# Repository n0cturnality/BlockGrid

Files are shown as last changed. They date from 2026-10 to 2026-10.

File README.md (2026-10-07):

<p align="center">
  <picture>
    <source media="(prefers-color-scheme: dark)" srcset="docs/images/blockgrid-wordmark-dark.svg">
    BlockGrid
  </picture>
</p>

<h3 align="center">A desk-size Bitcoin dashboard built on a HUB75 LED matrix and an ESP32</h3>

<br>

<p align="center">
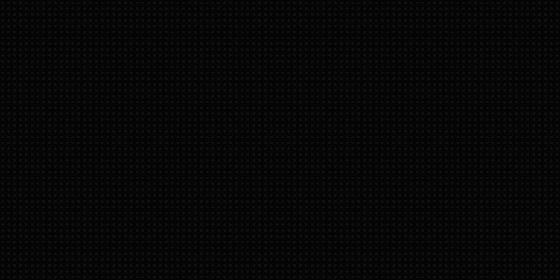
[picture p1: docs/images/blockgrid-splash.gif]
The boot splash: green digital rain of katakana and digits decodes into the word BLOCKGRID.
  
</p>

<p align="center">
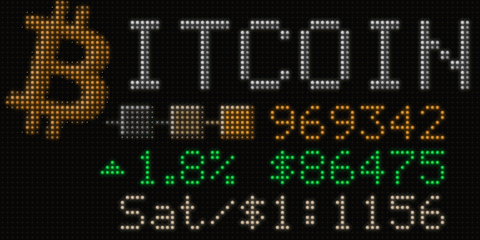
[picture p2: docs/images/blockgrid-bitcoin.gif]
The main screen with the Bitcoin logo: a new block slides onto the chain as the price in dollars changes, then it switches to euros and another block arrives with another price change.
  
  &nbsp;
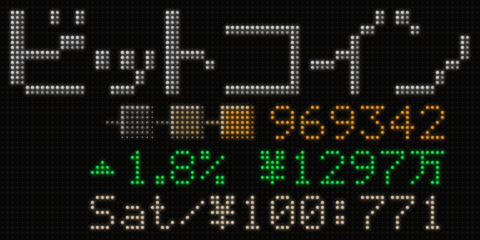
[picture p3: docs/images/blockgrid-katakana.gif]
The main screen with ビットコイン, Bitcoin in Japanese katakana, and the price in yen: two new blocks arrive, each with a price change.
  
</p>

BlockGrid shows the current block height, the price and its 24-hour change, and how many sats a dollar, euro or ¥100 buys. Two optional buttons on the back adjust the brightness and switch between the different looks and currency pairs. Everything else, from Wi-Fi to data sources, is set on a web page from your phone or computer.

<p align="center">
  <a href="https://n0cturnality.github.io/BlockGrid/">Live demo</a>
  &nbsp;
  <a href="#what-you-need">Build your own</a>
</p>

<br>

## Features

**Display**
- **Block height:** the chain tip, checked every 60 seconds.
- **Price:** in USD, EUR or JPY, with the 24-hour change and sats per $1, €1 or ¥100. Yen is shown in 万 (units of 10,000), the way large amounts are written in Japan.
- **Price effect:** roll, flash, sweep or none.
- **Two looks:** the Bitcoin logo, or ビットコイン in Japanese katakana.
- **Brightness:** 21 steps from 1 to 255, plus display off.
- **Flicker-free output:** double-buffered DMA drive of the HUB75 panel, at 6-bit colour per channel.

**Data sources**
- **Block height:** the mempool.space REST API, failing over to blockstream.info, or **your own node**: a mempool instance on a Start9, Umbrel or similar, over HTTP or HTTPS (self-signed certificates accepted), with the public APIs as fallback.
- **Price:** CoinGecko, failing over to mempool.space for the price and Coinbase for the 24-hour change. Polling interval adjustable from 30 seconds to 10 minutes (default 5).
- **Rate-limit handling:** after a 403 or 429 from CoinGecko it backs off for 10, then 30, then 60 minutes. When a source fails, the last good values stay on screen and are flagged as stale.

**Setup and control**
- **Captive-portal Wi-Fi setup:** BlockGrid starts its own password-protected access point. Joining it from a phone opens the setup page automatically, with a scan of nearby networks and their signal strength; hidden networks can be entered by name.
- **Web control page:** served at `http://blockgrid-xxxx.local` (mDNS) or the device's IP address. It covers brightness, display on/off, look, currency, price effect, data sources, polling interval, Wi-Fi and device status, and refreshes every 5 seconds from a JSON status endpoint, so changes made with the buttons show up on it.
- **Persistent settings:** stored in the ESP32's NVS flash, so they survive restarts and firmware updates.
- **Wi-Fi recovery:** reconnects with a back-off of 15 seconds rising to 60. After 3 minutes offline it falls back to the setup access point, retries the saved network every 2 minutes, and rejoins it automatically when it's back.
- **OTA updates:** firmware can be uploaded over Wi-Fi from the Arduino IDE (ArduinoOTA), protected by the device's setup password.

## What you need

<p align="center">
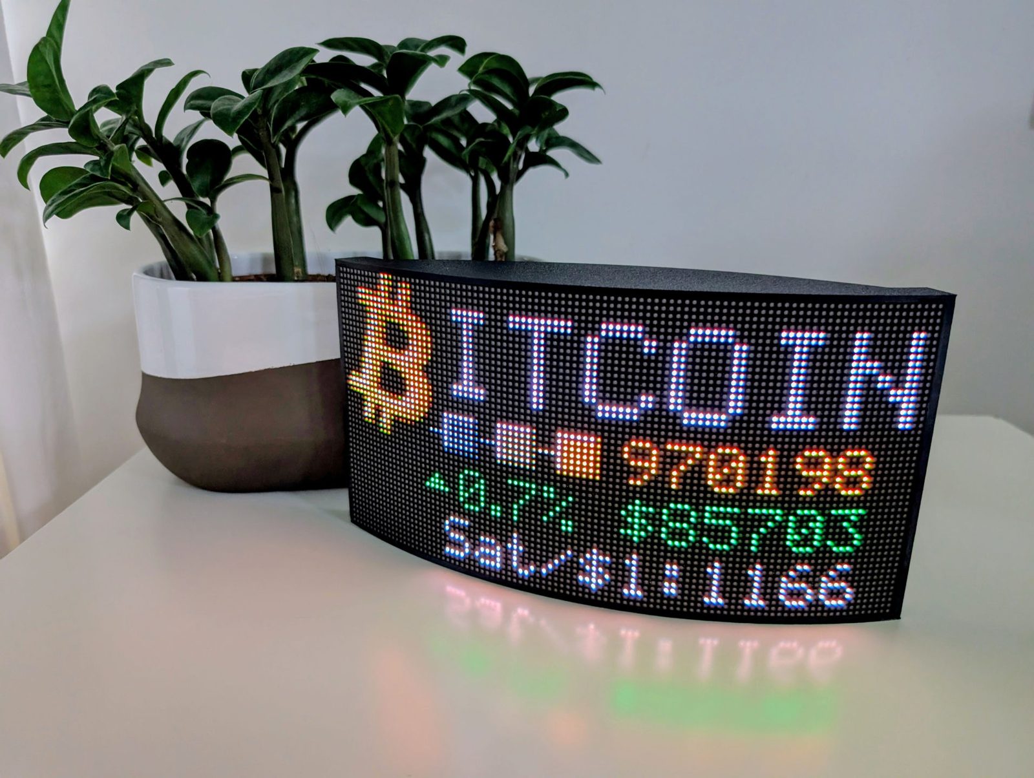
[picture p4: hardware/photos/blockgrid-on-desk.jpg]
The finished BlockGrid on a desk: a curved black case with the LED panel showing the Bitcoin logo, the block height and the price in dollars.
  
</p>

- a Waveshare flexible 96×48 LED matrix, 2.5 mm pitch (RGB-Matrix-P2.5-96x48-F), which comes with its ribbon and power cables
- an ESP32 DevKit V1 (30-pin) and a screw-terminal breakout board for it
- a 5 V, 2 A (or more) power supply and a panel-mount barrel jack
- a short USB-C extension cable, so you can reach the ESP32 from the back
- the 3D-printed enclosure, in a version with or without buttons, plus M3 screws, heat-set inserts and 10 × 2 mm magnets
- for the buttons version: two tactile buttons on a small prototype board
- recommended: two capacitors and a Schottky diode, to keep the power clean and protect your computer's USB port

<div align="center">

Hardware guide

<sub>Full parts list · wiring diagrams · button board layout · power and Wi-Fi tips · enclosure files · assembly photos</sub>

</div>

## Installing

### 1. Add the ESP32 boards to the Arduino IDE

1. Open **File → Preferences** (Windows and Linux) or **Arduino IDE → Settings** (macOS).
2. Under **Additional boards manager URLs**, paste this address. If the box already has one, add a comma first.

   ```
   https://espressif.github.io/arduino-esp32/package_esp32_index.json
   ```

3. Open **Tools → Board → Boards Manager…** (or the board icon in the left sidebar).
4. Search for **esp32** and install **esp32 by Espressif Systems**, version **3.3.12**. Not "Arduino ESP32 Boards", which is a different package. It's a large download.
5. Choose **Tools → Board → esp32 → ESP32 Dev Module**, or the entry for your board.
6. Plug the ESP32 in by USB and select its port under **Tools → Port**. No new port? The board's USB chip needs a driver. Most use a CP210x or CH340 chip (the name is printed next to the USB socket), and the driver is a free download from the chip maker.

### 2. Install the libraries

Open **Tools → Manage Libraries…** and install:

| Search for | Author | Version |
|---|---|---|
| ESP32 HUB75 LED MATRIX PANEL DMA Display | mrcodetastic | 3.0.15 |
| Adafruit GFX Library | Adafruit | 1.12.6 |
| Adafruit BusIO | Adafruit | 1.17.4 (offered with Adafruit GFX: choose "Install all") |
| ArduinoJson | Benoit Blanchon | 7.x |

Everything else (Wi-Fi, the web server, HTTPS, OTA) comes with the ESP32 board package. You don't need ESPAsyncWebServer or AsyncTCP.

### 3. Open the sketch and upload it

1. Download this repository (**Code → Download ZIP**) and unzip it.
2. Open `firmware/BlockGrid/BlockGrid.ino`. Leave `build_opt.h` next to it: it sets the panel's colour depth, and the sketch won't compile without it.
3. **Restart the Arduino IDE once.** This rebuilds the panel library with that colour depth. Skip it and mixed colours come out wrong: orange turns pink.
4. Check two settings near the top of the sketch:
   - **`PANEL_VERSION`:** check the label on the back of the panel. Ends in `-24S-A2.1` or `-24S-V2.1`? Use `1`. Ends in `-24S-A1`? Use `2` (the default).
   - **`HAS_BUTTONS`:** `1` for the enclosure with buttons, `0` for the one without. The web page can do everything the buttons do.
5. Click **Upload**.

### 4. Connect it to your Wi-Fi

1. The panel shows **WiFi Setup**, a network called **BlockGrid**, and a password.
2. Join that network on your phone. The setup page should open by itself; if not, browse to `http://192.168.4.1`.
3. Choose your home network, enter its password and tap **Connect**. BlockGrid restarts and joins it.
4. Open the control page at `http://blockgrid-xxxx.local`. The exact name and IP address are printed in the serial monitor (115200 baud) and shown on the page itself.

Each BlockGrid has its own setup password, which also protects over-the-air updates.

## Using it

**Buttons** (if fitted):

| | Short press | Hold |
|---|---|---|
| Top | Brighter | Next theme |
| Bottom | Dimmer (at the lowest level: display off) | Next currency |
| Both, for 3 s | | Restart |

**The web control page** does everything the buttons do, and also lets you choose the price effect, data sources, update interval, your node's address and the Wi-Fi network. It has no password, so anyone on your Wi-Fi can use it.

**Using your own node:** under **Data sources → Block height**, choose **My node** and enter the mempool app's address, as you'd type it into a browser (for example `https://192.168.1.50:50194`). BlockGrid asks your node first and falls back to the public servers if it doesn't answer. Self-signed certificates work fine.

## The simulator

`docs/index.html` simulates the panel and the control page; it's the same page as the [live demo](https://n0cturnality.github.io/BlockGrid/). Open it in any browser, with nothing to install. Its drawing code is a line-for-line copy of the sketch's, and the main screens are checked to match the sketch pixel for pixel. That makes it the place to try out a design change before touching the sketch.

## Repository layout

| Path | Contents |
|---|---|
| `firmware/BlockGrid/` | The Arduino sketch and `build_opt.h` |
| `docs/index.html` | The simulator (also the live demo, via GitHub Pages) |
| `docs/images/` | The GIFs and pictures on this page |
| `hardware/` | Parts list, wiring, button board layout and assembly |
| `hardware/enclosure/` | The enclosure files (STL and STEP), with and without buttons |
| `hardware/photos/` | Assembly photos |

## Credits

- [ESP32-HUB75-MatrixPanel-DMA](https://github.com/mrcodetastic/ESP32-HUB75-MatrixPanel-DMA) by mrcodetastic drives the panel.
- [Adafruit GFX](https://github.com/adafruit/Adafruit-GFX-Library) draws the text and graphics.
- [ArduinoJson](https://arduinojson.org/) by Benoit Blanchon reads the price data.
- The katakana wordmark and the 万 symbol are built from the [Misaki font](https://littlelimit.net/misaki.htm) bitmaps by Num Kadoma.
- Data comes from [mempool.space](https://mempool.space), [blockstream.info](https://blockstream.info), [CoinGecko](https://www.coingecko.com) and [Coinbase](https://www.coinbase.com). BlockGrid isn't affiliated with any of them.

## License

[MIT](LICENSE)

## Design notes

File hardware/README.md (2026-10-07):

# BlockGrid hardware

<p align="center">
  The finished BlockGrid on a desk: a curved black case with the LED panel showing the Bitcoin logo, the block height and the price in dollars.
</p>

The panel is flexible and curves around the 3D-printed case, held on by magnets. Inside, the ESP32 plugs into a screw-terminal breakout board, so nothing is soldered to the ESP32 itself. The power jack, a USB-C port for uploads and (optionally) two buttons are on the back.

The enclosure comes in two versions, [with and without buttons](#enclosure). Everything below applies to both unless it says "buttons version".

## Parts list

| Qty | Part | Notes |
|---|---|---|
| 1 | Waveshare flexible RGB LED matrix, 96×48, 2.5 mm pitch (RGB-Matrix-P2.5-96x48-F) | 4608 RGB LEDs, HUB75. The ribbon cable and power cable come with it. Two hardware versions exist; see [Panel version](#panel-version). |
| 1 | ESP32 DevKit V1 (ESP-WROOM-32), 30-pin | It has to be the 30-pin layout to fit the breakout board. Recent ones have a USB-C socket. |
| 1 | Screw-terminal breakout board for the 30-pin ESP32 DevKit V1 | The ESP32 plugs into it and every wire goes into a screw terminal. |
| 1 | 5 V power supply, 2 A minimum, with a barrel plug | Centre positive. Its plug must fit the jack below. |
| 1 | Barrel jack socket, 2.5 mm centre pin, panel mount with fixing nut | Fits the hole marked 5V on the back of the case. |
| 1 | Short USB-C extension cable, male to female | Brings the ESP32's USB port to the back of the case, for uploads and the serial monitor. Its socket end is glued in place; see [Assembly](#assembly). |
| 7 to 16 | 10 × 2 mm neodymium disc magnets, N52 recommended | Glued into the pockets around the rim of the case; they hold the panel. More magnets, firmer hold. |
| 8 | M3 × 6 mm countersunk (flat head) hex socket screws | 4 for the breakout board, 2 through the bottom of the base at each end to hold the case together, and 2 for the button board (buttons version). |
| 1 | M3 × 40 mm hex socket head cap screw | Holds the top and base together through the centre of the base, with two M3 × 6 screws at the ends. |
| 9 | M3 heat-set threaded inserts, 4 mm long, 5 mm outside diameter | All nine are melted into the printed case with a soldering iron. |
| 1 set | 3D-printed enclosure | With or without buttons; see [Enclosure](#enclosure). |
| | **Buttons version only** | |
| 2 | 6 × 6 mm tactile push buttons with a long round actuator | Long enough to reach through the back of the case. |
| 1 | Double-sided prototype board, 1.2" × 1.2" (30 × 30 mm), 8 × 11 holes | Holds the buttons; see [Button board](#button-board-buttons-version). |
| | 28 AWG wire in three colours | From the buttons to the breakout board. Yellow, blue and black in the photos. |
| | **Recommended** | |
| 1 | 1000 µF electrolytic capacitor, 10 V or higher | Across the panel's 5 V supply; see [Power](#power). |
| 1 | 100 µF electrolytic capacitor, 10 V or higher | Across the ESP32's VIN and GND; see [Power](#power). |
| 1 | 1N5819 Schottky diode (1 A, 40 V) | Between the supply and the ESP32's VIN; see [Power](#power). |

**Tools and supplies:** a soldering iron and solder (also used to set the inserts), heat-shrink tubing, glue for the magnets and the USB-C socket, a 2 mm and a 2.5 mm hex key, wire strippers, a small screwdriver for the terminals, and a multimeter for checking.

<p align="center">
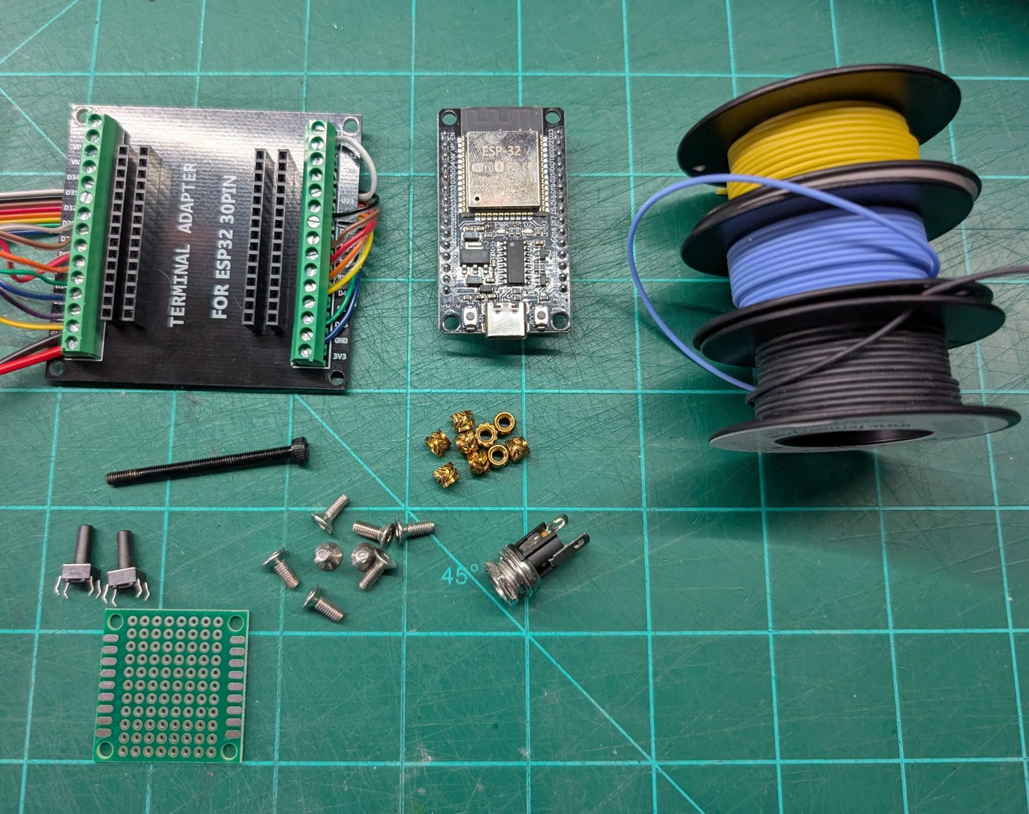
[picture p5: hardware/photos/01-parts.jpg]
The parts laid out: the ESP32 screw-terminal breakout board, the ESP32 DevKit, spools of yellow, blue and black wire, an M3 × 40 screw, brass heat-set inserts, countersunk M3 screws, two tactile buttons, a small prototype board and a panel-mount barrel jack.
  
</p>

## Wiring

### Panel (HUB75)

The panel's ribbon cable plugs into its HUB75 **input** connector (the arrows on the back of the panel point away from it). At the other end, each wire has its own small pin plug. Cut the pin plugs off, strip a few millimetres from each wire, tin the bare end with a little solder so the strands hold together, and screw each one into the breakout board.

<p align="center">
  Wiring diagram for the ESP32 screw-terminal breakout. Left terminals: D32 top button, D33 grey wire 8 E, D25 brown wire 1 R1, D26 red wire 2 G1, D27 orange wire 3 B1, D14 green wire 5 R2, D12 blue wire 6 G2, D13 purple wire 7 B2, GND yellow wire 4 and the power negative, VIN power positive. Right t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
</p>

Count the wires from the edge that goes to pin 1 of the plug, the one next to **R1** on the panel. On the rainbow cable that comes with the panel, wire 1 is **brown** and the colours run brown, red, orange, yellow, green, blue, purple, grey, white, black, then start again at brown. Cables vary, so check yours: if in doubt, test each wire against the pin labels printed next to the panel's connector, using a multimeter's continuity setting.

| Ribbon wire | Colour | HUB75 signal | ESP32 GPIO | Breakout terminal |
|---|---|---|---|---|
| 1 | brown | R1 | 25 | D25 |
| 2 | red | G1 | 26 | D26 |
| 3 | orange | B1 | 27 | D27 |
| 4 | yellow | GND | GND | GND |
| 5 | green | R2 | 14 | D14 |
| 6 | blue | G2 | 12 | D12 |
| 7 | purple | B2 | 13 | D13 |
| 8 | grey | E | 33 | D33 |
| 9 | white | A | 23 | D23 |
| 10 | black | B | 19 | D19 |
| 11 | brown | C | 5 | D5 |
| 12 | red | D | 17 | **TX2** |
| 13 | orange | CLK | 16 | **RX2** |
| 14 | yellow | LAT | 4 | D4 |
| 15 | green | OE | 15 | D15 |
| 16 | blue | GND | GND | GND |

GPIO 16 and 17 are labelled **RX2** and **TX2** on most breakout boards, not D16 and D17. Both ground wires (4 and 16) go to a GND terminal, one on each side of the board; each GND terminal also takes a second wire, from the power cable on one side and the buttons on the other.

The pins are set at the top of the sketch (`R1_PIN_DEFAULT` and so on) if your wiring differs.

### Power

The panel's power cable has a plug for the panel and two red and two black leads.

<p align="center">
  Power wiring. The panel's power cable has two red and two black leads. One pair goes to the barrel jack, red to the centre pin and black to the sleeve, with a 1000 microfarad capacitor across the jack's lugs, stripe to black. The other pair goes to the breakout board: black to GND, red through a 1N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
</p>

- **One red and black pair goes to the barrel jack:** red to the centre pin, black to the outer sleeve. Solder them and cover each joint with heat-shrink.
- **The other pair goes to the breakout board:** red to **VIN**, black to **GND**, the bottom two terminals of the left-hand row. This powers the ESP32 from the same supply.
- **The recommended parts**, if you fit them:
  - **1000 µF capacitor:** solder its legs to the jack's two lugs along with the wires, stripe (−) to the sleeve lug.
  - **1N5819 diode:** solder it into the red lead to VIN, close to the breakout board, with its band towards VIN. Cover it with heat-shrink.
  - **100 µF capacitor:** put its legs into the GND and VIN terminals together with the wires, stripe (−) to GND.

[Power](#power) explains why each one helps.

### Buttons (buttons version)

| Wire | Breakout terminal | Does |
|---|---|---|
| Yellow, from the top button | D32 (GPIO 32) | Brighter / next theme |
| Blue, from the bottom button | D18 (GPIO 18) | Dimmer / next currency |
| Black, from both buttons | GND | |

No resistors are needed: the ESP32's internal pull-ups are used.

## Button board (buttons version)

Both buttons sit on one small prototype board, which screws to the inside of the back panel with its buttons poking out through the case.

<p align="center">
  Button board layout, drawn from both sides. Button side: the top button's legs in columns 4 and 6, rows 5 and 7; the bottom button's legs in columns 4 and 6, rows 8 and 10; screws in the top-right and bottom-left corner holes. Solder side: the yellow wire enters row 5 and is bridged to the top butt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
</p>

Columns and rows are counted from the **button side**, with column 1 on the left and row 1 at the top. On the solder side everything is mirrored, so column 1 is on the right.

1. **Fit the buttons on the button side.** The top button's legs go in columns 4 and 6, rows 5 and 7; the bottom button's in columns 4 and 6, rows 8 and 10. Keep the top-right and bottom-left corner holes clear: those are the screw holes.
2. **Solder all eight legs** on the solder side.
3. **Add the wires** in the next column out (column 7), each bridged with solder to the leg beside it:
   - **yellow** in row 5, to the top button's leg in row 5
   - **black** in row 7, bridged to the legs in rows 7 **and** 8, so one wire grounds both buttons
   - **blue** in row 10, to the bottom button's leg in row 10
4. **Check it with a multimeter.** Yellow to black should only connect while the top button is pressed, and blue to black only while the bottom button is pressed. If a pair connects all the time, that button is turned 90°: rotate it.

<table>
  <tr>
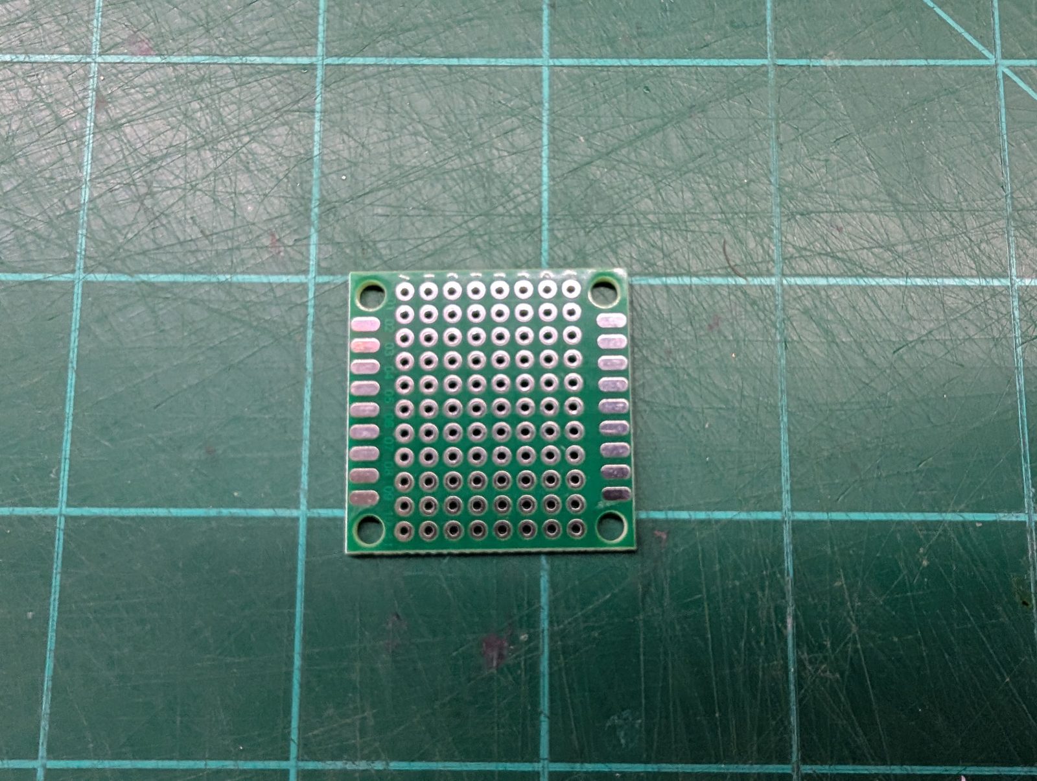
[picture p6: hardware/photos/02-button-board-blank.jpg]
The bare prototype board: 8 by 11 holes with a mounting hole in each corner and a row of pads down each side.
    <td width="33%"></td>
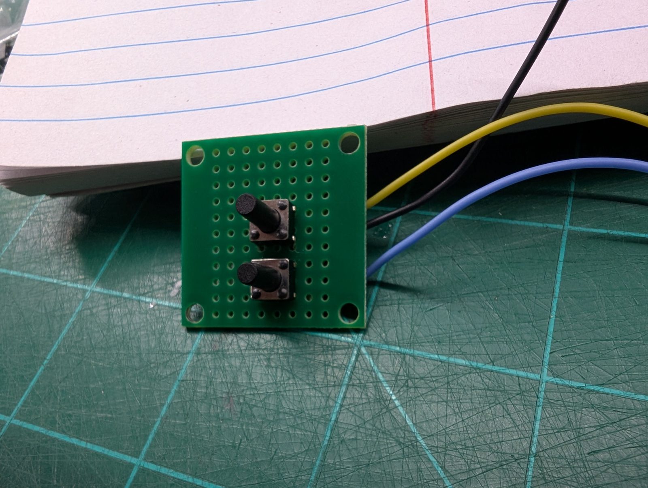
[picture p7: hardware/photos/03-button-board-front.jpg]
The button side: two tactile buttons with long black actuators, one above the other, a little right of centre.
    <td width="33%"></td>
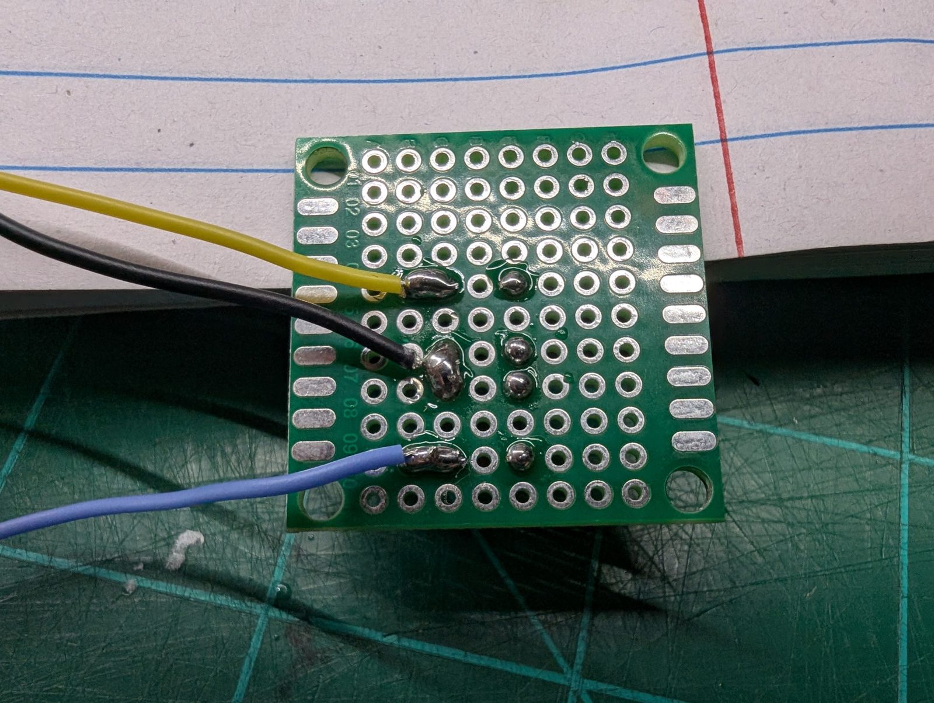
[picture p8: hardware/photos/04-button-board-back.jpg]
The solder side: yellow, black and blue wires soldered into the board and bridged to the button legs.
    <td width="33%"></td>
  </tr>
  <tr>
    <td align="center"><sub>The bare board</sub></td>
    <td align="center"><sub>Button side</sub></td>
    <td align="center"><sub>Solder side</sub></td>
  </tr>
</table>

## Panel version

Waveshare sells two versions of this panel. The label on the back tells them apart:

| Label ends in | `PANEL_VERSION` | Difference |
|---|---|---|
| `-24S-A2.1` or `-24S-V2.1` | `1` | The original panel. Some are printed V2.1, but they are still version 1. |
| `-24S-A1` | `2` (default) | SM5368 row drivers, red and blue swapped. The sketch handles both; the wiring is the same. |

## Power

- **The panel and the ESP32 share one 5 V supply:** the panel through its power cable, the ESP32 through the breakout board's VIN terminal.
- **The grounds must be connected:** the ESP32's GND and the panel's GND, both through the power cable and through the ribbon cable's ground wires.
- **BlockGrid draws about 0.4 A at full brightness,** Wi-Fi included, so a 2 A supply has plenty of headroom. Every LED at full white draws about 2.5 A, but BlockGrid never shows that. See [Measured current](#measured-current).
- **Restarting on its own** usually means the 5 V supply is dipping. The serial log's first line after a restart says "brownout" when that's the cause.

### Measured current

| Screen | Brightness | Current at 5 V |
|---|---|---|
| Every LED full white (a test, not something BlockGrid shows) | 255 | about 2.5 A |
| BlockGrid, normal use, Wi-Fi included | 255 (maximum) | about 0.4 A |

BlockGrid draws so much less because most of its screen is black and its text is a thin pixel font. At its default brightness of 60 it draws less still.

### Two capacitors (recommended)

The panel doesn't draw a steady current. Its LEDs are switched on and off thousands of times a second, so the current comes in sharp spikes. The ESP32 adds spikes of its own: each Wi-Fi transmission briefly draws several hundred milliamps. On thin or long power wires those spikes become dips and ripple in the 5 V supply, which can restart the ESP32 (a brownout) or disturb its Wi-Fi.

Two capacitors smooth this out by supplying the spikes from close by:

- **1000 µF across the barrel jack's lugs.** It covers the LEDs' current spikes, so they don't pull the supply down for everything else.
- **100 µF across the breakout board's VIN and GND terminals.** It covers the Wi-Fi bursts, so the ESP32 never sees its own supply sag.

Use electrolytic capacitors rated **10 V or more**. They're polarised: the stripe marks the **negative (−) leg**, which goes to GND. Fitted the wrong way round, they can fail violently.

### A Schottky diode (recommended)

The ESP32 is powered from the 5 V supply through VIN. Plugging in a USB cable (to upload or to watch the serial monitor) connects a second 5 V source: your computer's USB port. The two can then feed each other. The supply can push current back into the computer's USB port, and if the supply is off, the computer tries to power the whole panel through the USB cable, far beyond what a USB port is made for.

A diode in the supply line to the ESP32 lets current flow only one way: from the supply into the ESP32, never back.

- **Fit a 1N5819** (or similar) in the red lead to the VIN terminal. The **stripe (cathode) faces the ESP32**.
- **Why Schottky:** a Schottky diode loses only about 0.3 V, against roughly 0.7 V for an ordinary diode. That keeps VIN near 4.7 V, comfortably above what the ESP32's 3.3 V regulator needs.
- **It only carries the ESP32's current,** well under 1 A, so a 1 A diode is plenty. The panel stays connected straight to the supply.

Many ESP32 DevKit boards already have a diode between the USB socket and VIN, but not all do, and it's hard to tell from the outside. The external diode covers both cases. With it in place, you can leave USB plugged in while the supply is on.

## Wi-Fi interference

The panel is electrically noisy. Its data lines switch millions of times a second, the ribbon cable acts like a small antenna, and the LED current spikes travel down the power wires. Close to the ESP32's antenna, that noise can drown out the 2.4 GHz Wi-Fi signal.

**Signs:** a weak Wi-Fi signal on the control page's Device card, dropouts, a slow control page, or price and block updates failing now and then.

**What helps:**

- **Keep the ESP32's antenna clear.** The antenna is the end of the module with the zig-zag copper trace, opposite the USB socket. Keep it away from the ribbon wires, the power wires and metal (screws, inserts, magnets).
- **Keep the ribbon wires short** and route them away from the antenna.
- **Fit the two capacitors** described under [Power](#power). Less noise on the 5 V line means less of it reaches the ESP32's radio.
- **Check the signal** on the control page's Device card: −70 dBm or stronger (closer to zero) is comfortable. If it's weaker, try moving BlockGrid closer to your router.

The firmware helps too: it drives the panel at the library's default 8 MHz rather than faster, and keeps Wi-Fi power saving off, so the connection stays responsive.

## Enclosure

<p align="center">
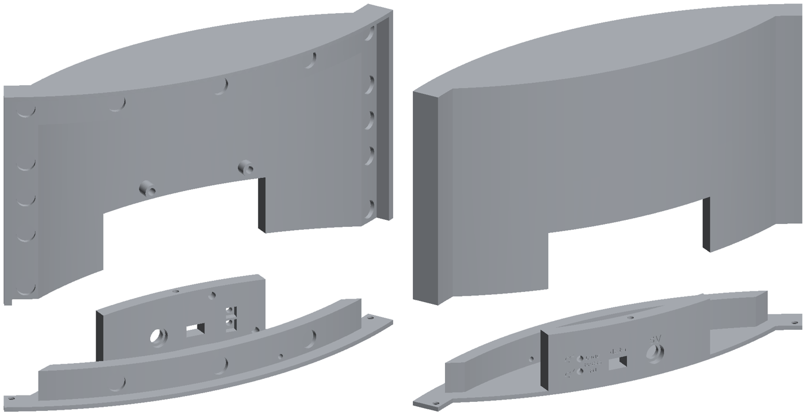
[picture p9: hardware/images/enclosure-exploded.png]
The two printed parts, pulled apart, seen from the front and from the back. The top is a curved shell with magnet pockets around its front rim; the base fits into the cutout at the bottom of the top and carries the back panel with the buttons, the USB-C opening and the barrel jack hole.
  
</p>

The case is two printed parts: the **top**, the curved shell the panel sits on, and the **base**, which closes the bottom and carries the back panel. The pockets around the front rim hold the magnets. Three screws through the bottom of the base hold the two together: an M3 × 40 in the centre and an M3 × 6 at each end.

Print the top and **one** of the two bases:

| Part | Files | Sketch setting |
|---|---|---|
| Top | `HUB75_enclosure_top.stl` | |
| Base with buttons | `HUB75_enclosure_base.stl` | `HAS_BUTTONS 1` |
| Base without buttons | `HUB75_enclosure_base_no_buttons.stl` | `HAS_BUTTONS 0` |

The files are in [`enclosure/`](enclosure/). Each part also comes as a `.step` file, for editing in Fusion or any other CAD program.

### Print settings

| Setting | Value |
|---|---|
| Material | PLA+ |
| Layer height | 0.2 mm |
| Walls | 3 |
| Infill | 20% |
| Supports | Yes, tree supports (the slicer's default) |
| Brim | Mouse ears |

Print each part the way round shown in the picture: the top standing on its edge, the base lying flat. The parts are about 241 mm long, so they need a large bed; on a smaller one, print them one at a time, diagonally if needed.

<p align="center">
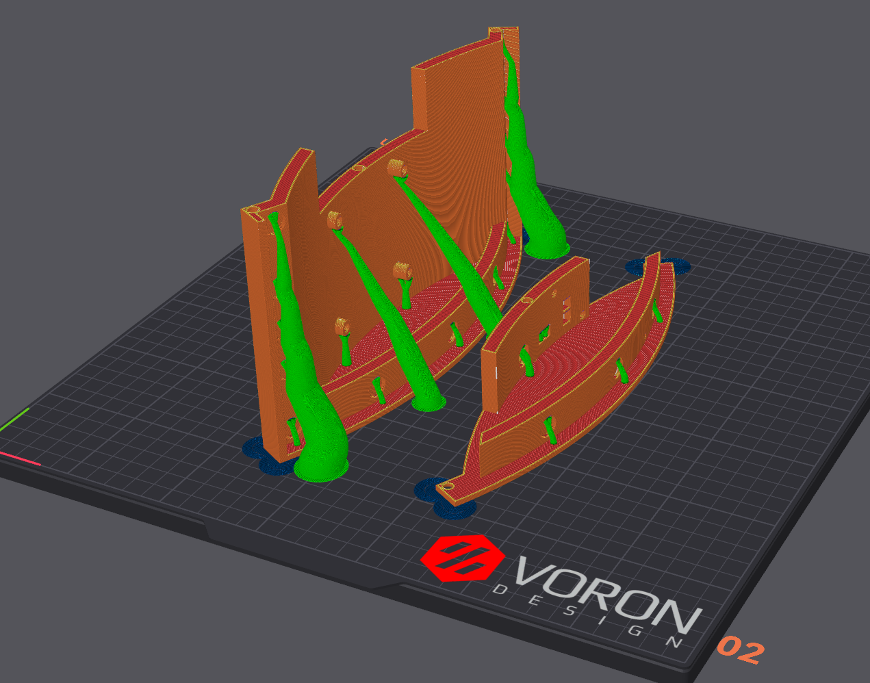
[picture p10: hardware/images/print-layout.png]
The two parts laid out in the slicer: the top standing on its edge with green tree supports under its overhangs, the base lying flat beside it, and small mouse-ear brims at the corners.
  
</p>

The base without buttons doesn't need the buttons, the prototype board, the 28 AWG wire or the button board's two screws. The web control page does everything the buttons do.

## Assembly

1. **Print the enclosure** and melt the heat-set inserts into their holes with a soldering iron.
2. **Glue the magnets** into the pockets around the rim. If the round pads on the back of your panel are magnets too, check that each magnet attracts the panel at that spot before you glue it, rather than pushing it away.
3. **Screw the breakout board** to the inside of the case with four M3 × 6 screws, and plug the ESP32 in with its USB socket towards the back opening.
4. **Fit the back panel parts:** the barrel jack through the hole marked 5V, held by its nut; the USB-C extension (see below); and (buttons version) the [button board](#button-board-buttons-version) with two M3 × 6 screws, buttons out.

   **The USB-C extension:** plug its male end into the ESP32, then line its female end (the socket) up with the opening marked "data", so the socket sits straight in the opening. Fix it with a little glue where the socket meets the inside of the case and the edges of the opening. This keeps it aligned and stops it being pushed back into the case when you plug a cable in. Use only a little, and keep glue out of the socket itself. Let it set before plugging anything in.

5. **Wire the power, the panel and the buttons** as described under [Wiring](#wiring).
6. **Upload the sketch and test it** before closing up, through the USB-C port on the back. See [Installing](../README.md#installing).
7. **Join the top and the base** from underneath: the M3 × 40 screw through the centre of the base, and an M3 × 6 screw at each end.
8. **Plug the ribbon cable and power cable into the panel,** then lay the panel onto the front of the case. The magnets hold it in place.

<table>
  <tr>
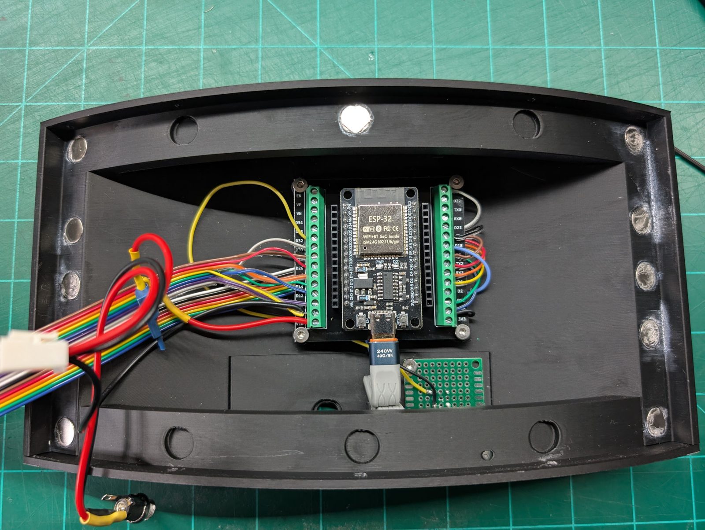
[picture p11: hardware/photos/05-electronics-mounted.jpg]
Inside the case: the ESP32 on its screw-terminal breakout board, the ribbon wires and the power leads in the terminals, the USB-C extension plugged in, and the button board below it.
    <td width="50%"></td>
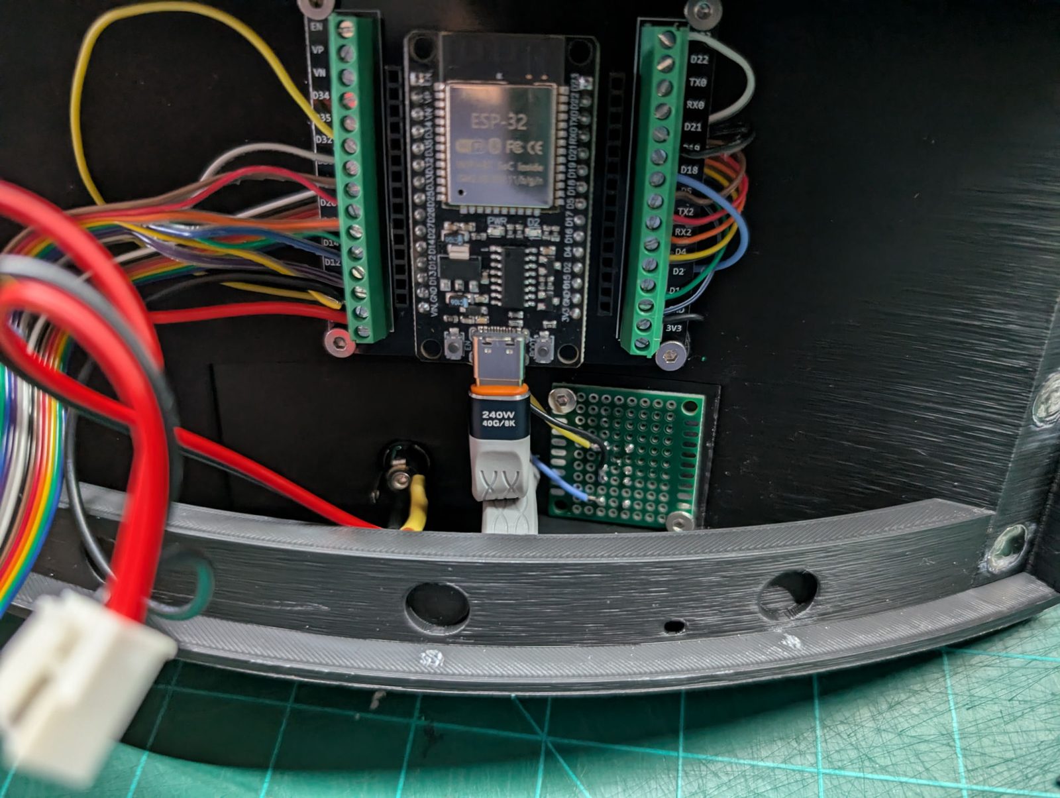
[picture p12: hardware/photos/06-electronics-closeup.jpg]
Close-up of the breakout board, the USB-C extension and the button board screwed in place, with the barrel jack beside them.
    <td width="50%"></td>
  </tr>
  <tr>
    <td align="center"><sub>Electronics in place</sub></td>
    <td align="center"><sub>USB-C extension, barrel jack and button board</sub></td>
  </tr>
  <tr>
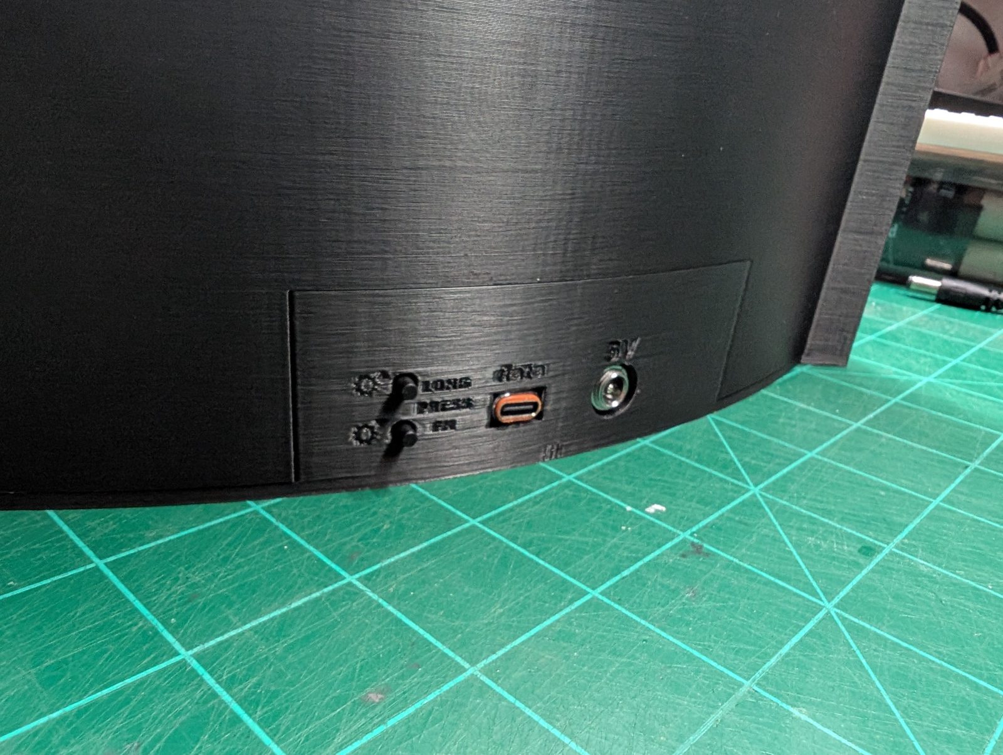
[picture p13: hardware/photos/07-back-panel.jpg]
The back of the case: the two buttons with their labels, the USB-C port marked data, and the barrel jack marked 5V.
    <td width="50%"></td>
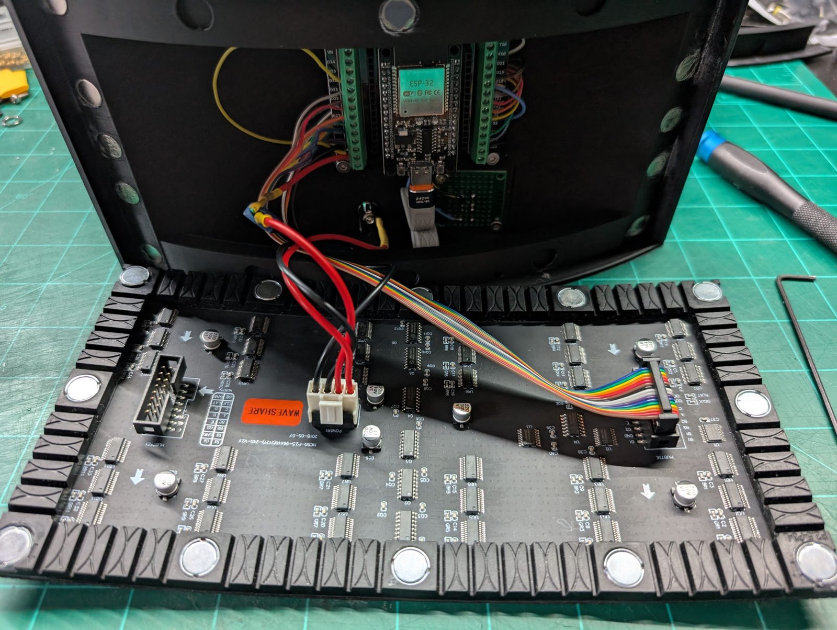
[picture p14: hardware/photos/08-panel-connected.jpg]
The panel lying face down in front of the open case, with the ribbon cable and the power cable plugged into its back.
    <td width="50%"></td>
  </tr>
  <tr>
    <td align="center"><sub>The back: buttons, USB-C and power</sub></td>
    <td align="center"><sub>Panel connected, before fitting</sub></td>
  </tr>
  <tr>
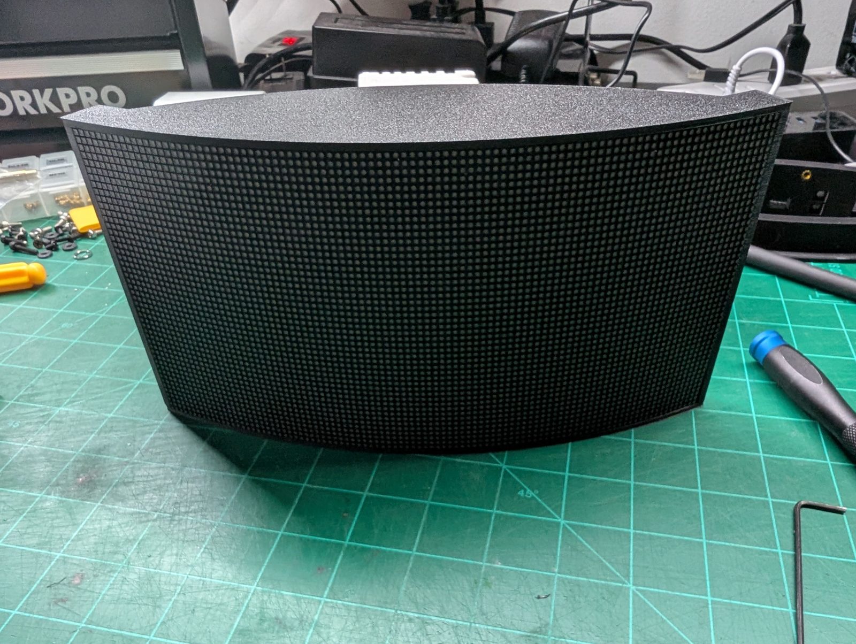
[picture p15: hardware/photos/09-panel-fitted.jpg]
The finished case with the panel fitted, switched off.
    <td width="50%"></td>
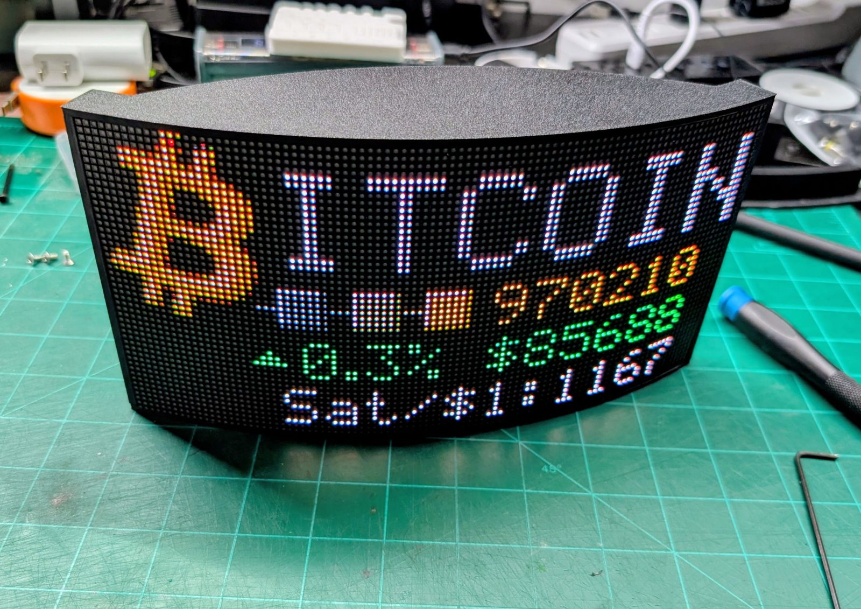
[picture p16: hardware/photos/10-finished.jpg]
The finished BlockGrid switched on, showing the Bitcoin logo, the block height, the price and sats per dollar.
    <td width="50%"></td>
  </tr>
  <tr>
    <td align="center"><sub>Panel fitted</sub></td>
    <td align="center"><sub>Finished</sub></td>
  </tr>
</table>

## Troubleshooting

| Symptom | Fix |
|---|---|
| Jumbled image, rows lit in the wrong places | Wrong `PANEL_VERSION` (see [Panel version](#panel-version)), or two ribbon wires swapped (see [Wiring](#panel-hub75)). |
| Red and blue swapped | Wrong `PANEL_VERSION`. |
| One colour missing, or the image torn into strips | A ribbon wire loose in its terminal or in the wrong one; see [Wiring](#panel-hub75). |
| Orange looks pink, tan looks mint | `build_opt.h` isn't in the sketch folder, or the Arduino IDE wasn't restarted after adding it. |
| Nothing on the panel, ESP32 runs | Check the 5 V feed to the panel and the shared ground. |
| Random restarts | Power supply too weak or a voltage drop in the wiring; fit the capacitors. See [Power](#power). |
| Weak Wi-Fi, dropouts, failed updates | Noise from the panel reaching the antenna; see [Wi-Fi interference](#wi-fi-interference). |
| A button does nothing, or acts as if held down | Check its wire and the GND wire; if it acts as if held, the button is turned 90°. See [Button board](#button-board-buttons-version). |
| No port in the Arduino IDE | Install the USB driver for the board's CP210x or CH340 chip, and check the USB-C extension supports data, not just charging. |

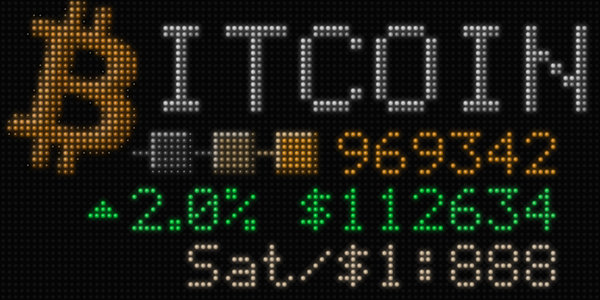
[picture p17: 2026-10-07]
docs/images/blockgrid.png

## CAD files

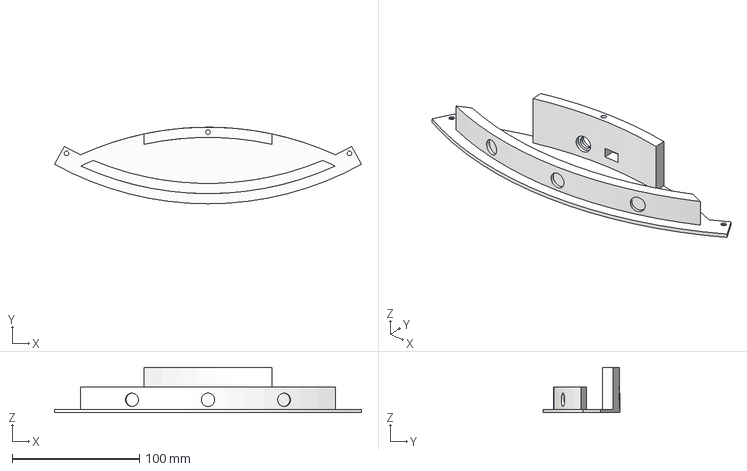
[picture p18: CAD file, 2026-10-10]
hardware/enclosure/HUB75_enclosure_base_no_buttons.step
241.2 x 60.2 x 35.5 mm

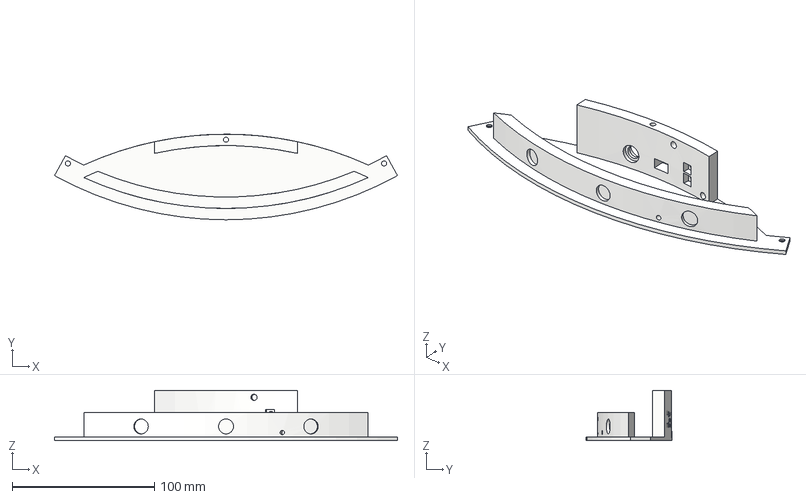
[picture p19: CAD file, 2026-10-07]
hardware/enclosure/HUB75_enclosure_base.step
241.2 x 60.2 x 35.5 mm

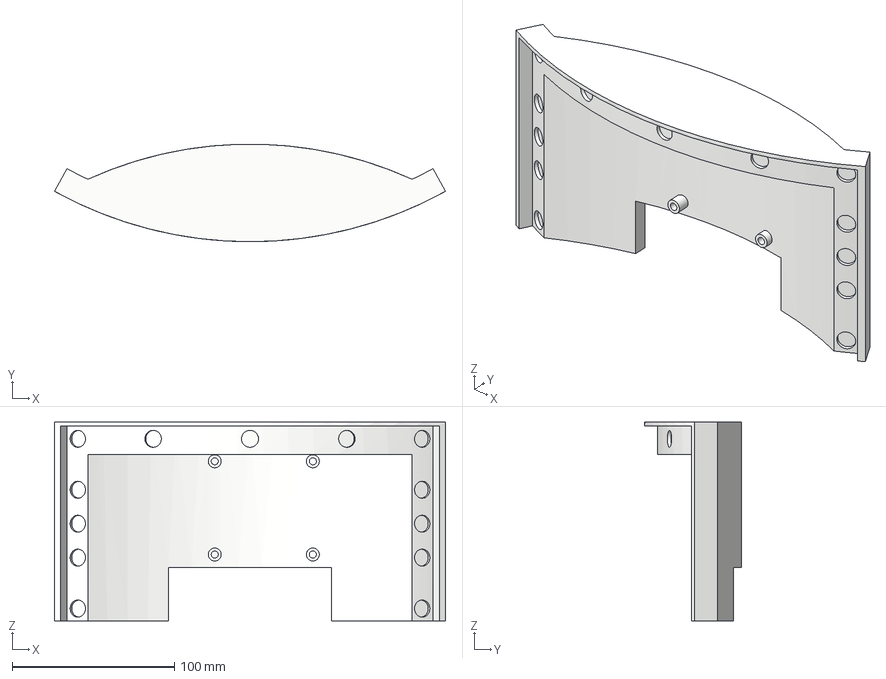
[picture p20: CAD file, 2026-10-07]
hardware/enclosure/HUB75_enclosure_top.step
241.2 x 60.1 x 122.5 mm

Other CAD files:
hardware/enclosure/HUB75_enclosure_base.stl
hardware/enclosure/HUB75_enclosure_base_no_buttons.stl
hardware/enclosure/HUB75_enclosure_top.stl

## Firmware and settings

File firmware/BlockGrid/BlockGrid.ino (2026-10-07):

// ---------------------------------------------------------------------------
// BlockGrid v1.0
//
// A desk-size Bitcoin dashboard for an ESP32 driving a Waveshare
// RGB-Matrix-P2.5-96x48-F (96x48 HUB75) LED panel: the current block height,
// the price in USD, EUR or JPY with its 24-hour change, and sats per $1, €1
// or ¥100. Wi-Fi is set up through a captive portal; everything else is set
// on a web control page or with two optional buttons.
//
// Before uploading:
//  - set PANEL_VERSION and HAS_BUTTONS below
//  - keep build_opt.h next to this file, and restart the Arduino IDE once
//    after adding it (it sets the panel library's colour depth)
//
// https://github.com/n0cturnality/BlockGrid
// MIT License, (c) 2026 n0cturnality. See LICENSE.
// ---------------------------------------------------------------------------

#define BLOCKGRID_VERSION "1.0"

#include <ESP32-HUB75-MatrixPanel-I2S-DMA.h>
#include <WiFi.h>
#include <WiFiClientSecure.h>
#include <HTTPClient.h>
#include <ArduinoJson.h>
// Built-in synchronous web server (part of the ESP32 board package). Used
// instead of ESPAsyncWebServer/AsyncTCP: the async one runs its own task
// with a 16 KB stack, and keeping that alive while on Wi-Fi left too little
// free memory for the HTTPS price fetches (they failed with -1). This one
// needs no task of its own — loop() serves requests between its other work.
#include <WebServer.h>
#include <DNSServer.h>   // setup mode's captive portal (see handleNotFound())
#include <Preferences.h>
#include <ArduinoOTA.h>
#include <ESPmDNS.h>
#include <atomic>
#include <esp_timer.h>
#include <stdint.h>
#include <math.h>
#include <esp_heap_caps.h> // for heap_caps_get_largest_free_block() — total free bytes alone doesn't show fragmentation; this does

// ---------- Physical buttons: fitted or not ----------
// 1 = the two push buttons are fitted (brightness / brand / currency /
//     hold-both-to-reboot, as well as the web control page).
// 0 = a display built without buttons: everything is done from the web
//     control page (http://blockgrid-xxxx.local). The button pins are left
//     alone and never read, so nothing needs to be connected to them.
#define HAS_BUTTONS 1

// ---------- Pin definitions ----------
#define R1_PIN_DEFAULT  25
#define G1_PIN_DEFAULT  26
#define B1_PIN_DEFAULT  27
#define R2_PIN_DEFAULT  14
#define G2_PIN_DEFAULT  12
#define B2_PIN_DEFAULT  13

#define A_PIN_DEFAULT   23
#define B_PIN_DEFAULT   19
#define C_PIN_DEFAULT   5
#define D_PIN_DEFAULT   17
#define E_PIN_DEFAULT   33

#define LAT_PIN_DEFAULT 4
#define OE_PIN_DEFAULT  15
#define CLK_PIN_DEFAULT 16

// Two independent buttons, each doing double duty: short press adjusts
// brightness (top button = up, bottom button = down), long press cycles
// branding (top) or currency (bottom). Both wired to GND with the
// internal pull-up enabled (INPUT_PULLUP) — no external resistors needed.
// Idle = HIGH, pressed = LOW.
#define BUTTON_BRAND_PIN    32
#define BUTTON_CURRENCY_PIN 18   // not GPIO33: that pin is the HUB75 panel's E address line (E_PIN_DEFAULT)
#define BUTTON_DEBOUNCE_MS 50UL

// Short press = brightness step (fires on release). Long press = the
// existing brand/currency cycling (fires the instant the hold crosses this
// threshold, not on release, so it feels responsive rather than delayed).
#define LONG_PRESS_THRESHOLD_MS 600UL
// Holding BOTH buttons together this long triggers a manual reboot —
// deliberately much longer than LONG_PRESS_THRESHOLD_MS so it reads as a
// clearly distinct, deliberate gesture rather than an extension of the
// normal single-button long press.
#define REBOOT_HOLD_MS 3000UL
// Brightness runs 1–255 (0 is "display off", a separate switch). The
// buttons step through BRIGHTNESS_LEVELS: small steps at the dim end, where
// the eye notices each one most, about a third brighter each step at the
// bright end. The web page's −/+ use the same levels, and its slider the
// same kind of curve.
// Very low levels: the panel library dims by switching the LEDs on for a
// few clock ticks per refresh, so near the bottom there are few ticks to
// share out and mixed colours (orange, the rain's dim greens) can shift.
// Pure red, green, blue and white stay true. Raise BRIGHTNESS_MIN if the
// lowest levels don't look right on your panel.
#define BRIGHTNESS_MIN  1
#define BRIGHTNESS_MAX  255
const uint8_t BRIGHTNESS_LEVELS[] = { 1, 2, 3, 4, 5, 6, 8, 10, 13, 17, 22, 28, 36, 46, 60, 77, 100, 128, 165, 210, 255 };
#define NUM_BRIGHTNESS_LEVELS (sizeof(BRIGHTNESS_LEVELS) / sizeof(BRIGHTNESS_LEVELS[0]))

// ---------- Panel config ----------
#define PANEL_RES_X 96
#define PANEL_RES_Y 48
#define PANEL_CHAIN 1

// Which hardware version of the Waveshare RGB-Matrix-P2.5-96x48-F is
// connected. Check the silkscreen on the back of the panel:
//   "...-24S-A2.1"  -> 1  (original version: 3-to-8 row decoders on A-E)
//   "...-24S-V2.1"  -> 1  (the same original version, printed V2.1 on some)
//   "...-24S-A1"    -> 2  (newer version: SM5368 row drivers)
// V2 needs different row driving (per Waveshare's own V2 instructions) and
// has its red and blue data lines the other way round; the wiring is the
// same for both. See the panel config block in setup().
#define PANEL_VERSION 2

// Colour depth per channel: 6 bits. The display's two frame buffers come out
// of the same memory the HTTPS price and block fetches need, and at the
// library's default 8 bits (~74 KB) the secure connections ran short
// ("BIGNUM - Memory allocation failed", "Generic error"). 6 bits (~55 KB)
// frees ~18 KB, and costs little: every colour is already stored as 5-6
// bits per channel (RGB565) before it reaches the panel.
//
// The depth MUST be set in the file build_opt.h, in this sketch's folder,
// which holds one line:   -DPIXEL_COLOR_DEPTH_BITS=6
// The HUB75 library picks its colour-correction table when the library
// itself is compiled, so a depth set only here in the sketch leaves it on
// its 8-bit table and mixed colours come out wrong. build_opt.h reaches the
// library's compile too. After adding or changing it, restart the Arduino
// IDE so the library is rebuilt.
#ifndef PIXEL_COLOR_DEPTH_BITS
#error "Colour depth not set: put build_opt.h (one line: -DPIXEL_COLOR_DEPTH_BITS=6) in this sketch's folder, then restart the Arduino IDE so the library is rebuilt"
#endif

// ---------- Timing ----------
// How often the price and block height are checked is set on the web
// control page (30 s to 10 min, default 5 min) — see updateIntervalMs().
#define WIFI_TIMEOUT_MS      15000UL  // 15 s per connection attempt (see WIFI_CONNECT_ATTEMPTS)
// Wi-Fi lost while running: BlockGrid keeps the last data on screen and
// keeps trying the home network — 15 s, then 30 s, then every minute between
// fresh attempts. After WIFI_FALLBACK_SETUP_MS without it, it switches to
// Wi-Fi setup mode, so a network that's gone for good (a phone hotspot,
// say) can be replaced. Setup mode keeps retrying the saved network every
// AP_RETRY_SAVED_MS and restarts normally when it answers, so a router
// restart still sorts itself out.
#define WIFI_RETRY_FIRST_MS   15000UL
#define WIFI_RETRY_MAX_MS     60000UL
#define WIFI_LOST_GRACE_MS     3000UL  // ignore blips shorter than this
#define WIFI_FALLBACK_SETUP_MS (3UL * 60UL * 1000UL)   // offline this long → setup mode
// In Wi-Fi setup mode with a saved network (it couldn't connect at boot,
// e.g. the router was still starting after a power cut): try the saved
// network again this often, for WIFI_TIMEOUT_MS each time, and restart
// normally once it answers.
#define AP_RETRY_SAVED_MS    120000UL
#define HTTP_TIMEOUT_MS       5000UL  // 5 s per-request timeout
// Boot splash timing — see the phase-by-phase comment in setup() for how
// these fit together (resolve, then fetch, then hold-while-raining,
// then gradual fade-out, then hold on the text alone).
#define SPLASH_POST_RESOLVE_HOLD_MS 2400UL // rain keeps flowing for this long after the word finishes decoding
#define RAIN_FADEOUT_MS             1100UL // existing rain dies out over this long (no new glyphs spawn); the GRID sweep plays at the start of it
#define RAIN_TEXT_ALONE_HOLD_MS     2100UL // once the rain's gone, hold on the bare word alone this long before switching to real data

// Sanity floor for block height responses. Bitcoin's height only increases;
// this just guards against displaying 0 / garbage on a bad response. Bump it
// up over time if you want a tighter check — it doesn't need to be exact.
#define MIN_PLAUSIBLE_BLOCK_HEIGHT 850000UL

// ---------- Image / logo ----------
typedef struct {
    const uint16_t *data;
    uint16_t width;
    uint16_t height;
    uint8_t dataSize;
} tImage;

// Bitcoin logo, 21x28 RGB565 — generated from the official high-res PNG
// with a subtle bevel (2px bevel, 30% highlight / 30% shadow) computed at
// full resolution, then area-averaged down so edges stay anti-aliased.
// Light from the top-left, matching the blockchain blocks. Identical to
// LOGO_DATA in matrix_sim_v3_1.html.
static const uint16_t image_data_logo[588] = {
    0x0000, 0x0000, 0x0000, 0x0000, 0x0000, 0x0000, 0x0000, 0x0000, 0x0000, 0x0000, 0xB3C6, 0xB3A5, 0x51A1, 0x0000, 0x0000, 0x0000, 0x0000, 0x0000, 0x0000, 0x0000, 0x0000,
    0x0000, 0x0000, 0x0000, 0x0000, 0x0000, 0x0000, 0x0000, 0x0000, 0x0000, 0x0820, 0xF549, 0xDC44, 0x6A01, 0x0000, 0x59E3, 0xB3A5, 0x7222, 0x0000, 0x0000, 0x0000, 0x0000,
    0x0000, 0x0000, 0x0000, 0x0000, 0x1060, 0x0020, 0x0000, 0x0000, 0x0000, 0x3942, 0xFD49, 0xC3A2, 0x3900, 0x0000, 0xA386, 0xF4E7, 0xBB62, 0x0000, 0x0000, 0x0000, 0x0000,
    0x0000, 0x0000, 0x0000, 0x0000, 0xA386, 0xECE7, 0xB3A5, 0x7263, 0x3121, 0x82C5, 0xF508, 0xBB62, 0x0840, 0x0000, 0xE4C9, 0xDC24, 0x7A41, 0x0000, 0x0000, 0x0000, 0x0000,
    0x0000, 0x0000, 0x0000, 0x0000, 0xE4A7, 0xECA5, 0xF4C5, 0xFD07, 0xFD27, 0xFD6A, 0xECC6, 0xCBC2, 0x51A2, 0x3942, 0xFD6A, 0xCBC3, 0x4961, 0x0000, 0x0000, 0x0000, 0x0000,
    0x0000, 0x0000, 0x0000, 0x0020, 0x7221, 0xA302, 0xE443, 0xFCE5, 0xFD27, 0xFD28, 0xE464, 0xF4C5, 0xFD07, 0xFD49, 0xFD49, 0xCBC2, 0x4961, 0x0000, 0x0000, 0x0000, 0x0000,
    0x0000, 0x0000, 0x0000, 0x0000, 0x0000, 0x0000, 0x6A02, 0xFD07, 0xFD07, 0xCBC2, 0xB342, 0xCBC2, 0xDC23, 0xEC85, 0xEC85, 0xF484, 0xFCE6, 0xBBC4, 0x3921, 0x0000, 0x0000,
    0x0000, 0x0000, 0x0000, 0x0000, 0x0000, 0x0000, 0x51A3, 0xFD6A, 0xF507, 0xBB82, 0xB362, 0x61E1, 0x92A1, 0xCBC2, 0xDC02, 0xEC63, 0xF4E5, 0xFCE5, 0xF4C4, 0x8282, 0x0000,
    0x0000, 0x0000, 0x0000, 0x0000, 0x0000, 0x0000, 0x8B05, 0xFD6A, 0xECC6, 0xBB62, 0xA302, 0x0000, 0x0000, 0x0020, 0x51A1, 0xDC02, 0xF4A3, 0xFCE5, 0xF4A4, 0xEC63, 0x59C1,
    0x0000, 0x0000, 0x0000, 0x0000, 0x0000, 0x0000, 0xCC68, 0xFD6A, 0xDC44, 0xBB62, 0x7221, 0x0000, 0x0000, 0x0000, 0x0000, 0x20A0, 0xECA5, 0xFD06, 0xF4A4, 0xDC22, 0xBB62,
    0x0000, 0x0000, 0x0000, 0x0000, 0x0000, 0x1060, 0xF56A, 0xFD6A, 0xCBE3, 0xBB62, 0x4961, 0x0000, 0x0000, 0x0000, 0x0000, 0x0000, 0xBBE6, 0xFD49, 0xECA5, 0xCBA2, 0xD3E2,
    0x0000, 0x0000, 0x0000, 0x0000, 0x0000, 0x49A2, 0xFD6A, 0xF528, 0xC382, 0xBB62, 0x1880, 0x0000, 0x0000, 0x0000, 0x0000, 0x0020, 0xE4E9, 0xFD6A, 0xE464, 0xBB62, 0xAB22,
    0x0000, 0x0000, 0x0000, 0x0000, 0x0000, 0x8B05, 0xFD6A, 0xF507, 0xD3E2, 0xE423, 0x9B24, 0x61E2, 0x3101, 0x20A1, 0x3922, 0xABC7, 0xFD8B, 0xF528, 0xC382, 0xB342, 0x7201,
    0x0000, 0x0000, 0x0000, 0x0000, 0x0000, 0xCC48, 0xFD6A, 0xE465, 0xBB62, 0xDC03, 0xECA5, 0xF506, 0xFD28, 0xFD49, 0xFD6A, 0xFD8B, 0xED08, 0xBB82, 0xB342, 0xA302, 0x1060,
    0x0000, 0x0000, 0x0000, 0x0000, 0x1040, 0xF56A, 0xFD6A, 0xCBC3, 0xB342, 0xA2E2, 0xC3A2, 0xD402, 0xE423, 0xEC84, 0xF4E6, 0xF507, 0xC3A2, 0xBB62, 0x7221, 0x1060, 0x0000,
    0x0000, 0x0000, 0x0000, 0x0000, 0x4982, 0xFD6A, 0xF528, 0xBB82, 0xBB62, 0x1880, 0x0000, 0x28C0, 0x6A01, 0xC3A2, 0xE443, 0xF463, 0xDC23, 0xF483, 0xC3C3, 0x1880, 0x0000,
    0x0000, 0x0000, 0x0000, 0x0000, 0x8AE5, 0xFD6A, 0xECC6, 0xBB62, 0xAB22, 0x0000, 0x0000, 0x0000, 0x0000, 0x0020, 0x8281, 0xF4A3, 0xFCC5, 0xFCC5, 0xF4A3, 0xC3A2, 0x0000,
    0x0000, 0x0000, 0x0000, 0x0000, 0xC448, 0xFD6A, 0xDC45, 0xBB62, 0x7A41, 0x0000, 0x0000, 0x0000, 0x0000, 0x0000, 0x0000, 0xB384, 0xFD07, 0xFCE5, 0xE443, 0xDC02, 0x4140,
    0x0000, 0x9325, 0x6202, 0x59E3, 0xF56B, 0xFD6A, 0xCBE3, 0xBB62, 0x4961, 0x0000, 0x0000, 0x0000, 0x0000, 0x0000, 0x0000, 0x7AA4, 0xFD49, 0xFD07, 0xD3E2, 0xC3A2, 0x61C1,
    0x51C3, 0xFD6A, 0xFD28, 0xFD6A, 0xFD8B, 0xF528, 0xC3A2, 0xBB82, 0x1880, 0x0000, 0x0000, 0x0000, 0x0000, 0x0000, 0x0000, 0xBC08, 0xFD6A, 0xF506, 0xC3A2, 0xBB62, 0x4961,
    0xBBC5, 0xEC84, 0xDC23, 0xE464, 0xE464, 0xE443, 0xDC02, 0xEC63, 0xDC66, 0x9B24, 0x6203, 0x3942, 0x3101, 0x4982, 0xABA7, 0xFD8B, 0xFD8A, 0xEC84, 0xBB62, 0xB362, 0x1880,
    0x20A0, 0x59A1, 0x8AA1, 0xC3A2, 0xD3E2, 0xEC83, 0xD3E2, 0xDC23, 0xF4C5, 0xFD07, 0xFD28, 0xFD28, 0xFD49, 0xFD6A, 0xFD8B, 0xFD8B, 0xECC6, 0xC382, 0xAB42, 0x8A81, 0x0000,
    0x0000, 0x0000, 0x0000, 0x0000, 0x51A2, 0xFD28, 0xBB82, 0xC3A2, 0xD3E2, 0xE443, 0xEC84, 0xDC24, 0xE485, 0xECA5, 0xE485, 0xD403, 0xBB62, 0xAB42, 0xAB22, 0x2080, 0x0000,
    0x0000, 0x0000, 0x0000, 0x0000, 0x7264, 0xF508, 0xBB82, 0x1880, 0x3900, 0xECC6, 0xD424, 0xBB62, 0xCBC2, 0xCBC2, 0xC3A2, 0xBB82, 0xBB62, 0x92A1, 0x20A0, 0x0000, 0x0000,
    0x0000, 0x0000, 0x0000, 0x0000, 0xABC7, 0xE4A6, 0xA302, 0x0000, 0x1880, 0xFD6A, 0xCBE3, 0x59A1, 0x1880, 0x3100, 0x4120, 0x3900, 0x1880, 0x0000, 0x0000, 0x0000, 0x0000,
    0x0000, 0x0000, 0x0000, 0x0000, 0xE4C7, 0xD3E3, 0x7221, 0x0000, 0x51C3, 0xF549, 0xBB82, 0x28C0, 0x0000, 0x0000, 0x0000, 0x0000, 0x0000, 0x0000, 0x0000, 0x0000, 0x0000,
    0x0000, 0x0000, 0x0000, 0x0820, 0x6A01, 0x92C2, 0x4120, 0x0000, 0x9325, 0xE485, 0xB342, 0x0000, 0x0000, 0x0000, 0x0000, 0x0000, 0x0000, 0x0000, 0x0000, 0x0000, 0x0000,
    0x0000, 0x0000, 0x0000, 0x0000, 0x0000, 0x0000, 0x0000, 0x0000, 0x59C1, 0x9AE2, 0x8261, 0x0000, 0x0000, 0x0000, 0x0000, 0x0000, 0x0000, 0x0000, 0x0000, 0x0000, 0x0000,
};

const tImage logo = { image_data_logo, 21, 28, 16 };

// ビットコイン (Bittokoin, "Bitcoin" in katakana) — the authentic way
// Bitcoin is written in Japan; there's no kanji equivalent for it, and
// katakana is the correct form (loanwords use katakana). Sourced from the
// Misaki font's embedded bitmaps — same authoritative source as the 万/円
// icons — one 8x8 glyph per character (ビ, ッ, ト, コ, イ, ン), assembled
// into a single 48x8 wordmark image, white on black to match "ITCOIN"'s
// title color. 6 chars × 8px = 48px fits comfortably in the 72px title
// field (x=24 to x=96).
static const uint16_t image_data_bitcoinKatakana[384] = {
  0x0000, 0xFFFF, 0x0000, 0x0000, 0xFFFF, 0x0000, 0xFFFF, 0x0000, 0x0000, 0x0000, 0x0000, 0x0000, 0x0000, 0x0000, 0x0000, 0x0000, 0x0000, 0x0000, 0xFFFF, 0x0000, 0x0000, 0x0000, 0x0000, 0x0000, 0x0000, 0x0000, 0x0000, 0x0000, 0x0000, 0x0000, 0x0000, 0x0000, 0x0000, 0x0000, 0x0000, 0x0000, 0x0000, 0x0000, 0xFFFF, 0x0000, 0x0000, 0xFFFF, 0x0000, 0x0000, 0x0000, 0x0000, 0x0000, 0x0000,
  0x0000, 0xFFFF, 0x0000, 0x0000, 0x0000, 0x0000, 0x0000, 0x0000, 0x0000, 0x0000, 0x0000, 0x0000, 0x0000, 0x0000, 0x0000, 0x0000, 0x0000, 0x0000, 0xFFFF, 0x0000, 0x0000, 0x0000, 0x0000, 0x0000, 0x0000, 0xFFFF, 0xFFFF, 0xFFFF, 0xFFFF, 0xFFFF, 0xFFFF, 0x0000, 0x0000, 0x0000, 0x0000, 0x0000, 0x0000, 0xFFFF, 0x0000, 0x0000, 0x0000, 0x0000, 0xFFFF, 0x0000, 0x0000, 0x0000, 0x0000, 0x0000,
  0x0000, 0xFFFF, 0x0000, 0x0000, 0x0000, 0xFFFF, 0xFFFF, 0x0000, 0x0000, 0x0000, 0x0000, 0x0000, 0x0000, 0x0000, 0x0000, 0x0000, 0x0000, 0x0000, 0xFFFF, 0x0000, 0x0000, 0x0000, 0x0000, 0x0000, 0x0000, 0x0000, 0x0000, 0x0000, 0x0000, 0x0000, 0xFFFF, 0x0000, 0x0000, 0x0000, 0x0000, 0x0000, 0xFFFF, 0x0000, 0x0000, 0x0000, 0x0000, 0x0000, 0x0000, 0x0000, 0x0000, 0x0000, 0xFFFF, 0x0000,
  0x0000, 0xFFFF, 0xFFFF, 0xFFFF, 0xFFFF, 0x0000, 0x0000, 0x0000, 0x0000, 0xFFFF, 0x0000, 0xFFFF, 0x0000, 0xFFFF, 0x0000, 0x0000, 0x0000, 0x0000, 0xFFFF, 0xFFFF, 0xFFFF, 0x0000, 0x0000, 0x0000, 0x0000, 0x0000, 0x0000, 0x0000, 0x0000, 0x0000, 0xFFFF, 0x0000, 0x0000, 0x0000, 0x0000, 0xFFFF, 0xFFFF, 0x0000, 0x0000, 0x0000, 0x0000, 0x0000, 0x0000, 0x0000, 0x0000, 0x0000, 0xFFFF, 0x0000,
  0x0000, 0xFFFF, 0x0000, 0x0000, 0x0000, 0x0000, 0x0000, 0x0000, 0x0000, 0xFFFF, 0x0000, 0xFFFF, 0x0000, 0xFFFF, 0x0000, 0x0000, 0x0000, 0x0000, 0xFFFF, 0x0000, 0x0000, 0xFFFF, 0x0000, 0x0000, 0x0000, 0x0000, 0x0000, 0x0000, 0x0000, 0x0000, 0xFFFF, 0x0000, 0x0000, 0xFFFF, 0xFFFF, 0x0000, 0xFFFF, 0x0000, 0x0000, 0x0000, 0x0000, 0x0000, 0x0000, 0x0000, 0x0000, 0xFFFF, 0x0000, 0x0000,
  0x0000, 0xFFFF, 0x0000, 0x0000, 0x0000, 0x0000, 0x0000, 0x0000, 0x0000, 0x0000, 0x0000, 0x0000, 0xFFFF, 0x0000, 0x0000, 0x0000, 0x0000, 0x0000, 0xFFFF, 0x0000, 0x0000, 0x0000, 0x0000, 0x0000, 0x0000, 0x0000, 0x0000, 0x0000, 0x0000, 0x0000, 0xFFFF, 0x0000, 0x0000, 0x0000, 0x0000, 0x0000, 0xFFFF, 0x0000, 0x0000, 0x0000, 0x0000, 0x0000, 0x0000, 0x0000, 0xFFFF, 0x0000, 0x0000, 0x0000,
  0x0000, 0x0000, 0xFFFF, 0xFFFF, 0xFFFF, 0xFFFF, 0xFFFF, 0x0000, 0x0000, 0x0000, 0xFFFF, 0xFFFF, 0x0000, 0x0000, 0x0000, 0x0000, 0x0000, 0x0000, 0xFFFF, 0x0000, 0x0000, 0x0000, 0x0000, 0x0000, 0x0000, 0xFFFF, 0xFFFF, 0xFFFF, 0xFFFF, 0xFFFF, 0xFFFF, 0x0000, 0x0000, 0x0000, 0x0000, 0x0000, 0xFFFF, 0x0000, 0x0000, 0x0000, 0x0000, 0xFFFF, 0xFFFF, 0xFFFF, 0x0000, 0x0000, 0x0000, 0x0000,
  0x0000, 0x0000, 0x0000, 0x0000, 0x0000, 0x0000, 0x0000, 0x0000, 0x0000, 0x0000, 0x0000, 0x0000, 0x0000, 0x0000, 0x0000, 0x0000, 0x0000, 0x0000, 0x0000, 0x0000, 0x0000, 0x0000, 0x0000, 0x0000, 0x0000, 0x0000, 0x0000, 0x0000, 0x0000, 0x0000, 0x0000, 0x0000, 0x0000, 0x0000, 0x0000, 0x0000, 0x0000, 0x0000, 0x0000, 0x0000, 0x0000, 0x0000, 0x0000, 0x0000, 0x0000, 0x0000, 0x0000, 0x0000
};
const tImage bitcoinKatakanaImg = { image_data_bitcoinKatakana, 48, 8, 16 };

// ---------- Brand and currency cycling (two independent buttons) ----------
// Brand (logo + title, drawn at x=1,y=0 and x=24,y=6) and currency (which
// price/sats format the body uses) are independent choices — the brand
// button cycles one, the currency button cycles the other, so N brands and
// M currencies need N+M entries total instead of N×M combined ones.
enum class Currency : uint8_t { USD, JPY, EUR };   // saved in Preferences by this value: add new ones at the end
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
void loop() {
    // In AP mode only the setup page needs serving (OTA isn't started until
    // we're on the home WiFi network, in RUNNING/RECONNECTING state).
    if (currentState == DeviceState::AP_MODE) {
        dnsServer.processNextRequest();
        serveWeb();
        pollWifiScan();
        retrySavedNetworkFromSetup();
        delay(2);
        return;
    }

    if (otaInitialized) ArduinoOTA.handle();

    handleButtons();  // cheap poll — fine to run every loop pass
    pollWifiScan();     // the web page's Wi-Fi card
    processWifiJoin();

    unsigned long now = millis();

    // Wi-Fi lost: noticed within a few seconds (not only when a check is
    // due), then retried without blocking — the buttons and display keep
    // working meanwhile. See WIFI_RETRY_FIRST_MS.
    if (currentState == DeviceState::RUNNING) {
        if (WiFi.status() == WL_CONNECTED) wifiLostSinceMs = 0;
        else if (wifiLostSinceMs == 0) wifiLostSinceMs = now ? now : 1;
        else if (now - wifiLostSinceMs >= WIFI_LOST_GRACE_MS) {
            Serial.println("WiFi disconnected. Reconnecting...");
            WiFi.reconnect();
            reconnectStartMs = now;
            reconnectDelayMs = WIFI_RETRY_FIRST_MS;
            lastOfflineRedrawMs = now;
            currentState = DeviceState::RECONNECTING;
        }
    }
    if (currentState == DeviceState::RECONNECTING) {
        if (WiFi.status() == WL_CONNECTED) {
            Serial.printf("Reconnected after %lus.\n", (now - wifiLostSinceMs) / 1000UL);
            currentState = DeviceState::RUNNING;
            wifiLostSinceMs = 0;
            setupOTA();  // re-arm OTA in case the IP/mDNS state went stale
            lastPriceCheckMs = lastBlockCheckMs = 0;   // fresh data straight away
        } else if (now - wifiLostSinceMs >= WIFI_FALLBACK_SETUP_MS) {
            Serial.printf("No WiFi for %lus — switching to Wi-Fi setup mode\n", (now - wifiLostSinceMs) / 1000UL);
            saveBrightnessNow();
            startAccessPoint();   // keeps retrying the saved network (see retrySavedNetworkFromSetup())
            return;
        } else {
            if (now - reconnectStartMs >= reconnectDelayMs) {
                // A fresh attempt rather than waiting on a stuck one.
                Serial.printf("Still no WiFi (%lus) — trying again\n", (now - wifiLostSinceMs) / 1000UL);
                WiFi.disconnect();
                WiFi.begin(savedSsid.c_str(), savedPassword.c_str());
                WiFi.setSleep(false);
                reconnectStartMs = now;
                reconnectDelayMs = reconnectDelayMs * 2 > WIFI_RETRY_MAX_MS ? WIFI_RETRY_MAX_MS : reconnectDelayMs * 2;
            }
            // Keep the screen honest while offline: once the data is too old
            // it turns to ERR, as it would after failed checks.
            if (now - lastOfflineRedrawMs >= BLOCK_CHECK_MS) {
                lastOfflineRedrawMs = now;
                displayBitcoinInfo(currentSnapshot());
            }
        }
        return;
    }

    // Refresh data on first run (lastUpdateMs == 0) or after interval. In
    // practice lastUpdateMs is already set directly at the end of setup()
    // before loop() ever runs, but the == 0 check stays here as a safety
    // net in case that ever changes.
    if (lastUpdateMs == 0 || priceCheckDue() || blockCheckDue()) {
        if (WiFi.status() != WL_CONNECTED) return;   // handled above once it's been down a few seconds
        if (scanRunning) return;                     // a Wi-Fi scan takes a few seconds; fetch after it

        refreshBitcoinData();
    }
    // loop() returns immediately, so buttons and the web page stay responsive
}
